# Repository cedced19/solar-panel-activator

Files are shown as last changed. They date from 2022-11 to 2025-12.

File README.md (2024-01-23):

# solar-panel-activator
With solar-panel-watch, activate a switch if the solar panel production is beyound a certain value. 

Create a congig.h file:
```c
#define SSID "ssid"
#define PASSWORD "passwd"
```

Basic:
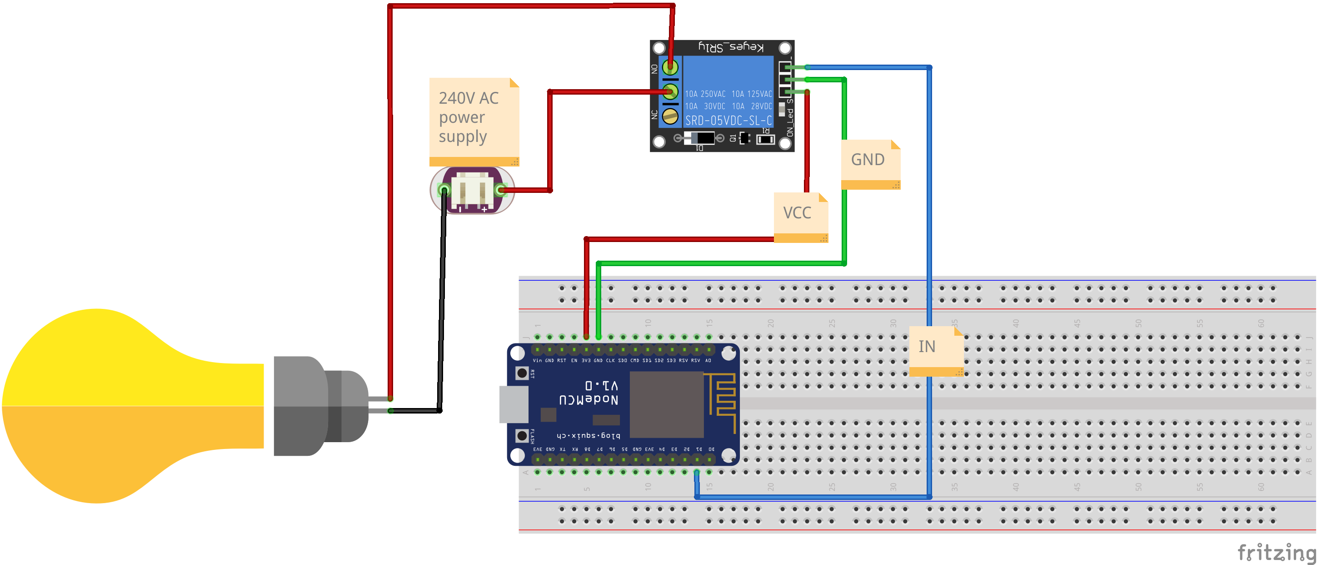
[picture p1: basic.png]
basic


Advanced:
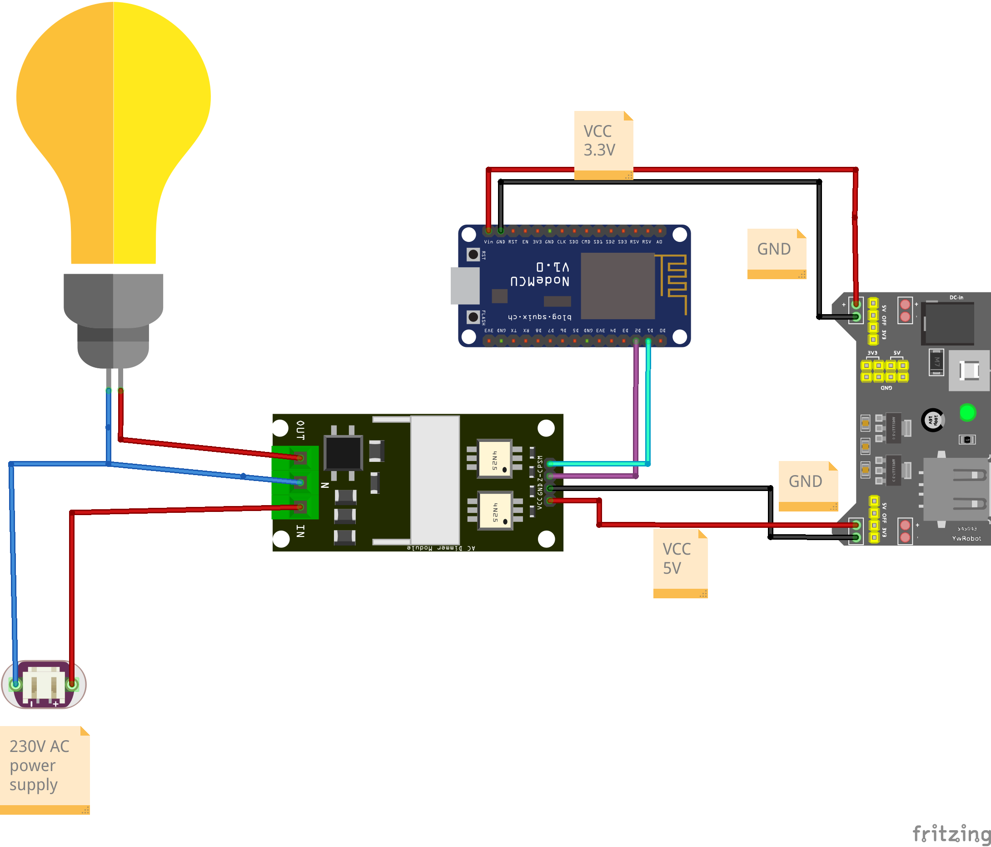
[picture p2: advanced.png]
advanced


Thermistor:
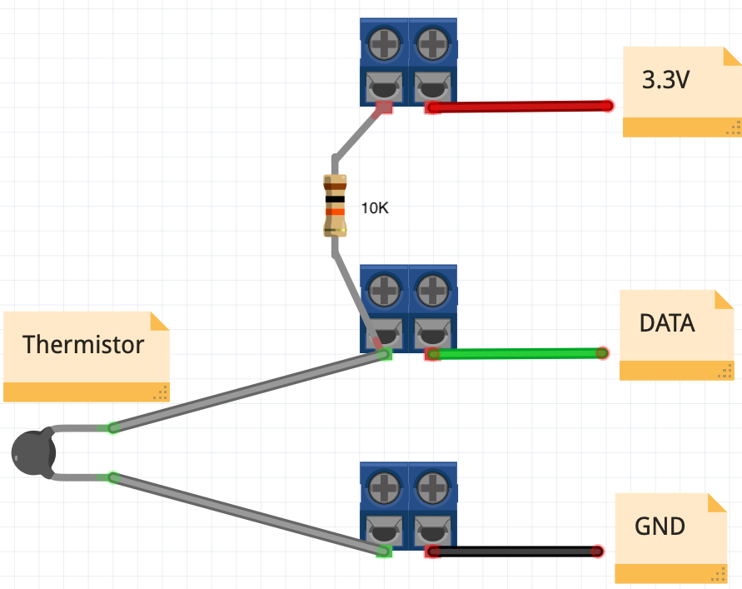
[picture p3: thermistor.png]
thermistor


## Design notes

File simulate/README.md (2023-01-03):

## Test

This is create a server to test.

```
python3 -m http.server 8001
```

Replace `http://192.168.0.62:8001/test.json` by `http://192.168.0.98:8889/api/device/id/1b9d8/advanced`

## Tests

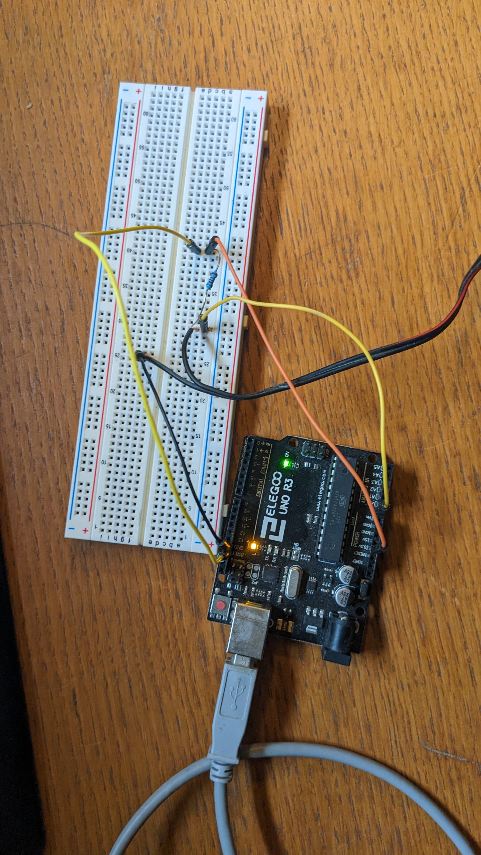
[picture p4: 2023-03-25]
test-dimmer-arduino/circuit.jpg

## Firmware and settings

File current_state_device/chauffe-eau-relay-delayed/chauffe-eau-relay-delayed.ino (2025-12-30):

#include <Arduino.h>

#include <ESP8266WiFi.h>

#include <ESP8266HTTPClient.h>

#include <WiFiClient.h>
#include <ArduinoJson.h>
#include "config.h"

int PSM = 05; // D1
int ZC = 04; // D2  
int relayPin = 12; // D6 (14 corresponding to D5 on some devices) 
int dimming = 128;  // Dimming level (0-128)  0 = ON, 128 = OFF

unsigned long relay_transition_time = 0;
bool relay_transitioning = false;
int target_dimming = 128;
bool relay_target_state = HIGH;


void ICACHE_RAM_ATTR zero_crosss_int(void);

// WiFi Parameters
const char* ssid = SSID;
const char* password = PASSWORD;

// Timers
unsigned long timer = 0;
unsigned long timer_prevent_failure = 0;
unsigned long timer_temperature = 0;
unsigned long timer_wifi = 0;

unsigned long time_limit = 1000;

// T law
// which analog pin to connect
#define THERMISTORPIN A0         
// resistance at 25 degrees C
#define THERMISTORNOMINAL 10000      
// temp. for nominal resistance (almost always 25 C)
#define TEMPERATURENOMINAL 25   
// The beta coefficient of the thermistor (usually 3000-4000)
#define BCOEFFICIENT 3950
// the value of the 'other' resistor
#define SERIESRESISTOR 10000    

void initWiFi() {
  WiFi.begin(ssid, password);
  WiFi.mode(WIFI_STA);
  WiFi.setSleepMode(WIFI_NONE_SLEEP);
  WiFi.setAutoReconnect(true);
  WiFi.persistent(true);

  while (WiFi.status() != WL_CONNECTED) {
    Serial.printf("[WIFI] Connecting...\n");
    digitalWrite(LED_BUILTIN, LOW);
    delay(1000);
  }
  Serial.printf("[WIFI] Connected\n");
  timer_wifi = millis();
}

void setup() {

  Serial.begin(115200);
  initWiFi();
  digitalWrite(LED_BUILTIN, HIGH); 
  
  
  dimming = 128;
  pinMode(PSM, OUTPUT);// Set AC Load pin as output
  attachInterrupt(digitalPinToInterrupt(ZC), zero_crosss_int, RISING);  // Choose the zero cross interrupt

  pinMode(relayPin, OUTPUT);
  digitalWrite(relayPin, HIGH);
}

// the interrupt function must take no parameters and return nothing
void zero_crosss_int()  // function to be fired at the zero crossing to dim the light
{
  // Firing angle calculation : 1 full 50Hz wave =1/50=20ms 
  // Every zerocrossing thus: (50Hz)-> 10ms (1/2 Cycle) For 60Hz => 8.33ms (10.000/120)
  // 10ms=10000us
  // (10000us - 10us) / 128 = 75 (Approx) For 60Hz =>65

  int dimtime = (75*dimming);    // For 60Hz =>65    
  delayMicroseconds(dimtime);    // Off cycle
  digitalWrite(PSM, HIGH);   // triac firing
  delayMicroseconds(100);         // triac On propogation delay (for 60Hz use 8.33)
  digitalWrite(PSM, LOW);    // triac Off
  //Serial.print("Trig\n");
}

void update() {
    WiFiClient client;
    HTTPClient http;
    Serial.print("[HTTP] begin...\n");
    if(http.begin(client, "http://192.168.0.87:8889/api/device/id/QQqR9/advanced/")) {
      int httpCode = http.GET();                                                   
      if (httpCode == 200 || httpCode == 304) {
        Serial.printf("[HTTP] GET... code: %d\n", httpCode);
        // Parsing
        StaticJsonDocument<200> root;
        
        DeserializationError error = deserializeJson(root, http.getString());

        // Test if parsing succeeds.
        if (error) {
          Serial.print("[JSON PARSER] deserializeJson() failed: ");
          Serial.println(error.f_str());
          Serial.print("[DECISION] Desactivating\n");
          safeDeactivate();
          return;
        }
        timer = millis();
        time_limit = root["time_limit"];
        int new_dimming = root["alpha"]; 
        if (new_dimming < 3 && new_dimming != 128) {
          new_dimming = 3;
        }
        
        // Handle state transitions with relay protection
        if (new_dimming == 128) {
          // Turning OFF
          Serial.print("[DECISION] Desactivating\n");
          safeDeactivate();
        } else {
          // Turning ON or changing brightness
          Serial.print("[DECISION] Activating\n");
          safeActivate(new_dimming);
        }
        Serial.print("[DECISION] Alpha = ");
        Serial.print(new_dimming);
        Serial.print("\n");

      } else {
        Serial.printf("[HTTP] GET... failed, error: %s\n", http.errorToString(httpCode).c_str());
        Serial.print("[DECISION] Desactivating\n");
        safeDeactivate();
      }
      http.end();
    } else {
      Serial.printf("[HTTP] Unable to connect\n");
      Serial.print("[DECISION] Desactivating\n");
      safeDeactivate();
    }
}

// Safe deactivation: dimmer to 0 first, then relay off
void safeDeactivate() {
  if (dimming != 128) {
    // First reduce dimming to minimum
    dimming = 128;
    target_dimming = 128;
    
    // Start transition timer for relay
    relay_transitioning = true;
    relay_transition_time = millis();
    relay_target_state = HIGH;
    
    Serial.print("[RELAY PROTECTION] Dimmer set to 0, waiting before opening relay\n");
  } else {
    // Already off, just ensure relay is open
    digitalWrite(relayPin, HIGH);
    relay_transitioning = false;
  }
}

// Safe activation: relay on first, then ramp up dimmer
void safeActivate(int new_dimming) {
  target_dimming = new_dimming;
  
  if (digitalRead(relayPin) == HIGH) {
    // Relay is currently open, need to close it first
    Serial.print("[RELAY PROTECTION] Closing relay first\n");
    

    // Keep dimming at safe level until relay settles
    dimming = 128; // Minimum safe value

    digitalWrite(relayPin, LOW);
    
    // Start transition timer for dimmer
    relay_transitioning = true;
    relay_transition_time = millis();
    relay_target_state = LOW;
    

  } else {
    // Relay already closed, safe to change dimming directly
    dimming = new_dimming;
    relay_transitioning = false;
  }
}

void handleRelayTransition() {
  if (relay_transitioning) {
    unsigned long elapsed = millis() - relay_transition_time;
    
    // Wait 100ms for relay contacts to settle
    if (elapsed >= 100) {
      if (relay_target_state == HIGH) {
        // Complete deactivation sequence
        digitalWrite(relayPin, HIGH);
        Serial.print("[RELAY PROTECTION] Relay opened safely\n");
      } else {
        // Complete activation sequence
        dimming = target_dimming;
        Serial.print("[RELAY PROTECTION] Dimmer ramped up safely to ");
        Serial.print(dimming);
        Serial.print("\n");
      }
      relay_transitioning = false;
    }
  }
}


void getTemperature() {
  char params[100];
  char temperatureString[6];
  WiFiClient clientTemp;
  HTTPClient httpTemp;

  float measure;
  float temperature;

  measure = analogRead(THERMISTORPIN);

  //Serial.print("measure analog reading "); 
  //Serial.println(measure);
  
  // convert the value to resistance
  measure = 1023 / measure - 1;
  measure = SERIESRESISTOR / measure;
  //Serial.print("Thermistor resistance "); 
  //Serial.println(measure);
  
  float steinhart;
  steinhart = measure / THERMISTORNOMINAL;     // (R/Ro)
  steinhart = log(steinhart);                  // ln(R/Ro)
  steinhart /= BCOEFFICIENT;                   // 1/B * ln(R/Ro)
  steinhart += 1.0 / (TEMPERATURENOMINAL + 273.15); // + (1/To)
  steinhart = 1.0 / steinhart;                 // Invert

  temperature = steinhart - 273.15;  // Temperature in degree celsius
  Serial.print("Temperature = ");
  Serial.print(temperature);
  Serial.println(" degree celsius");
  dtostrf(temperature, 4, 2, temperatureString);
  snprintf(params, 100, "var=%s", temperatureString);
  httpTemp.begin(clientTemp, "http://192.168.0.87:8889/api/device/id/QQqR9/control-variable/"); // specifie the address
  httpTemp.addHeader("Content-Type", "application/x-www-form-urlencoded");
  httpTemp.POST(params);    
  httpTemp.end();
  timer_temperature = millis();
}

void loop() {
  handleRelayTransition();
  // wait for WiFi connection
  if ((WiFi.status() == WL_CONNECTED)) {
    // Update alpha
    if(millis() > timer + time_limit) {
      update();
    }
    // Update temperature
    if(millis() > timer_temperature + 120000) { // each 2min = 120000ms
      getTemperature();
    }
  } else {
    // check WiFi Status and disconnect if necessary
    if (millis() > timer_wifi + 300000) { // each 5min if it fails
      Serial.println("[WIFI] Reconnecting to WiFi...");
      WiFi.disconnect();
      initWiFi();
    }
  }
  // stop each hour to prevent failure
  if(millis() > timer_prevent_failure + 3600000) {
    dimming = 128;
    digitalWrite(relayPin, HIGH);
    timer_prevent_failure = millis();
  }
}

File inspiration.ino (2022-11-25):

/*

Power_Router est un système qui permet d'utiliser l'excédent d'énergie autoproduit par 
l'allumage d'un appareil résistif (facteur de puissance proche de 1) ce qui évite l'injection 
au réseau public de distribution d'électricité.

Le principe de fonctionnement est le suivant :
- détection de phase entre courant et tension permet de savoir si on consomme ou bien on injecte
- en cas d'injection il se produit la mise en route progressive d'un dispositif d'absorption 
d'excédent de puissance 
- la mesure du courant permet d'ajuster au mieux le niveau d'absorption de cet excédent.
- Par ailleurs il est prévu une sortie temporisée de 30 secondes (paramétrable) lorsque le seuil 
d'injection est proche de 3W (paramétrable) permettant par exemple de couper l'injection d'une 
éolienne au profit de la charge de batteries. 

le programme prévoit :
- une sonde de tension : simple transfo 230V/5V Crête à Crête sur mi-tension (2.5V)
- une sonde de courant : 20A/25mA sur mi-tension (2.5V)
- un module de commande par triac
- un dispositif de détection de passage à zéro de la sinusoïde de tension secteur (par exemple 
l'optocoupleur H11AA1)
- la bibliothèque TimeOne.h à installer et disponible là : 
http://www.arduino.cc/playground/Code/Timer
- en option un afficheur LCD 1602 avec extension I2C

La gamme de puissances testée est va de 300 à 1000W

merci à Ryan McLaughlin <ryanjmclaughlin@gmail.com> pour avoir étudié et mis au point la partie 
commande du triac il y a quelques années et que j'ai repris dans ce programme :)
source : https://web.archive.org/web/20091212193047/http://www.arduino.cc:80/cgi-bin/yabb2/YaBB.pl?num=1230333861/15

_________________________________________________________________
|                                                               |
|       auteur : Philippe de Craene <dcphilippe@yahoo.fr        |
|           pour l' Association P'TITWATT                       |
_________________________________________________________________

Toute contribution en vue de l’amélioration de l’appareil est la bienvenue ! Il vous est juste
demandé de conserver mon nom et mon email dans l’entête du programme, et bien sûr de partager 
avec moi cette amélioration. Merci.

Récapitulatif des branchements :
 - broche A0 (analogique 0) => sonde de courant
 - broche A1 (analogique 1) => sonde de tension
 - broche A4 (analogique 4) => broche SDA sur LCD 
 - broche A5 (analogique 5) => broche SCL sur LCD
 - broche  2 (numérique 2)  => broche ZC (zero-cross) du module triac
 - broche  3 (numérique 3)  => LED indiquant le taux de pwm
 - broche 10 (numérique 10) => broche PWM (commande Triac) du module triac
 - brcohe 11 (numérique 11) => circuit de commande du délestage
 - broche 13 (numérique 13) => LED indiquant l'overflow

Chronologie des versions :
version 0.5 - 3 mai 2018     - boucle de décrémentation byDim --
version 0.8 - 5 juil. 2018   - 1ère version fonctionnelle, pb du pic de courant du triac 
version 1   - 6 juil. 2018   - ajout de la bibliothèque EmonLib.h pour mesure du secteur
version 1.4 - 7 juil. 2018   - simplification des tests sur sPower et byDim.
version 1.6 - 8 juil. 2018   - ajout LED d'overflow + optimisation des paramètres + iSeuilPoff
version 1.8 - 24 sept 2018   - ajout du pas variable sur byDim avec iDimStep
version 1.9 - 12 oct. 2018   - ajout d'une sortie temporisée de 5min à iSeuilPoff (25W) du seuil d'injection  
version 2.0 - 4 nov. 2018    - ajout d'un watchdog avec comptage de reset en EEPROM
version 2.2 - 7 nov. 2018    - iSeuilPtempo variable à part entière pour le délestage + correction coquille
version 2.3 - 16 dec 2018    - réaménagemet des messages console pour gagner du temps
version 2.4 - 12 jan 2019    - ajout d'un afficheur LCD 1602 avec extension I2C
version 3.2 - 17 jan 2019    - gain en performances en contournant EmonLib.h
version 3.2.4 - 1 mai 2020   - application filtre digital pass bas 

*/

#include <EEPROM.h>
#include <avr/wdt.h>    // documentation : https://tushev.org/articles/arduino/5/arduino-and-watchdog-timer
#include <TimerOne.h>   // librairie à installer depuis http://www.arduino.cc/playground/Code/Timer1
#include <LiquidCrystal_I2C.h> // librairie à installer depuis https://app.box.com/s/czde88f5b9vpulhf8z56

// Attention ! Renommer la librairie d'origine de l'IDE LiquidCrystal.h et LiquidCrystal.cpp

//  Affiche les mesures à la console cependant au détriment des performances
const bool bVerbose = false;       // pour le debugging
const bool bCalibration = false;   // pour la calibration

//
// Variables de calibration :
// Calibration des mesures des sondes pour avoir des valeurs correctes :
// en premier : fVCalibration doit être défini pour obtenir les 230V du secteur
// ensuite : fICalibration en comparant l'affichage de la console avec celui d’un wattmètre 
// pour s'approcher de la réalité. En l'absence de wattmètre effectuer le test avec une 
// charge résistive connue, par exemple une ampoule halogène neuve.
// REMARQUE : les variables de type float exigent un nombre à virgule
//
const float fVCalibration     = 0.826;  // pour la calibration de la tension
const float fICalibration     = 45; // pour la calibration de l'intensité
const float fPhaseCalibration = 0.7;   // valeur empirique compensant le déphasage lié aux capteurs...
const byte byTotalCount       = 20;    // nombre de demie-périodes étudiées pour la mesure

unsigned int iNombreIteration        = 0;       // nombre d'itérations durant les 20ms
unsigned int iTemps                  = 0;       // mesure du temps en secondes
const float fCyclesParSeconde        = 5.;
const float fMargeSecuriteWatt       = 0.;      // marge de sécurité en Watt pour être sûr de ne pas injecter
const int iCapaciteReservoirEnergie  = 3600;    // capacité du réservoir virtuel = 3600 joules
float fReservoirEnergie              = 0.;      // quantité d'énergie en joule stockée dans le réservoir virtuel

// Variables utiles au délestage
unsigned long iDelestStart    = 0;          // début du délestage
const float fDelestOn         = 30000.;     // seuil de puissance en mW pour démarrage du délestage
const float fBucketDelestOn   = 500.;       // seuil d'énergie en joules pour démarrage du delestage
const unsigned int iTempo     = 300;        // durée du délestage
bool bFlagDelest              = false;

// Détermination des entrées et sorties :
const byte byTriacPin             = 10;    // sortie numérique de commande de charge résistive
const byte byDelestPin            = 11;    // sortie temporisée à 5min à 20W du seuil 
const byte byTriacLedPin          = 3;     // sortie numérique pour la LED de test du triac
const byte byLimiteLedPin         = 13;    // sortie numérique pour la LED d'overflow
const byte byVoltCapteurPin       = 1;     // détecteur de tension entrée analogique 1
const byte byIntensiteCapteurPin  = 0;     // détecteur de courant entrée analogique 0
const byte byZeroCrossPin         = 2;     // détecteur de phase entrée digitale 2
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

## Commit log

2022-09-28 Add pin
2022-11-27 Update README;md
    [advanced.fzz, basic.fzz]
2023-01-09 Add relay
2023-02-09 Update pin
2023-03-25 Fix rights
    [advanced.fzz, basic.fzz]
2023-03-25 Add temperature test
2023-03-25 Add nodemcu temperature
2023-04-08 Add thermistor format
2025-12-30 Add a delay to open/close the relay
